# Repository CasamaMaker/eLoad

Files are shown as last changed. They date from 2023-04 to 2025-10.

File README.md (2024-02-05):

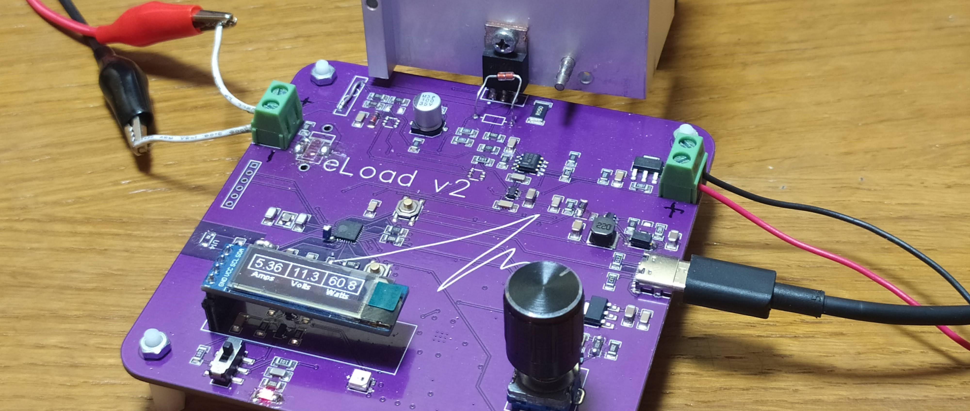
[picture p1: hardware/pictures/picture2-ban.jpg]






[__Project published on OSHWLAB__](https://oshwlab.com/canmarques/electronic-load_v2_copy)

# Electronic Load - 60W

This is a DIY project aimed at providing a practical, useful  and safe electronic load for people interested in electronics. While it is not be the most powerful electronic load available, it is designed to be easy to use and reliable, making it an excellent option for those looking for a DIY electronic load. We develop a HW and SW for complete integration, but you can use it as you want. Based in microcontroller ESP32-C3.

---

## Purpose

This project is designed for people who want to build their own electronic load for testing and evaluating power supplies, batteries, and other electronic components. It is a practical and affordable solution for those who do not want to spend a lot of money on a commercial electronic load but still want to have a reliable tool for their electronic projects.

## Features

The __Electronic Load - 60W__ has several features that make it a practical and useful tool, including:

- __25Vdc__ maximum voltage
- __5A__ maximum current
- __60W__ power output (_12V/5A_, depending on cooling system, Fan needed!!)
- Based in microcontroller __ESP32-C3__
- Reverse polarity voltage protection
- __Thermal protection__ to prevent avalanche breakdown due to temperature
- Overcurrent and overvoltage protection
- Adjustable current, voltage and power settings by fisical selector
- Switch to dis/enable load functions
- Easy-to-read display for current, voltage and power monitoring
- Easy-to-configure wifi _ssid_ and _psk_
- __Live graphic on web__ for current, tension and power monitoring
- Cooling fan output, 12Vdc/0.5A
- It is powered by a typical 5V USB-C power source

---

## Board connections
- USB to power up the LV site of board
- Vload input, where to connect the power supply to apply the load
- Power mosfet, is the main component that works in resistence part to to vary its resistance. I need a heatsink !!
- Fan output, to healp heatsink control mosfet temperature. For low power applications and having a good heatsink maybe it is not needed.
- eLoad switch enable and disable the mosfet gate directly, to stop or let run the load.

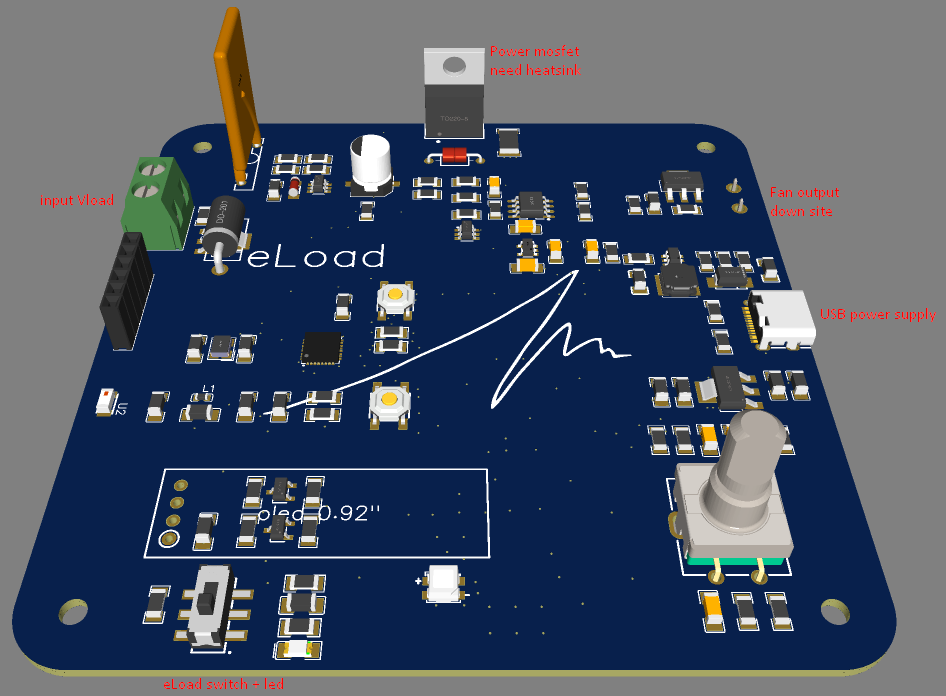
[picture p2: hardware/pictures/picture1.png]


---

## Monitoring web
When you plug in the USB power to eLoad electronics, it will start and in a few seconds will show a IP (if it can connecto to the wifi) or it wil generate an AP wifi (where you can configure wifi, if you want). At any case, you will see this website.

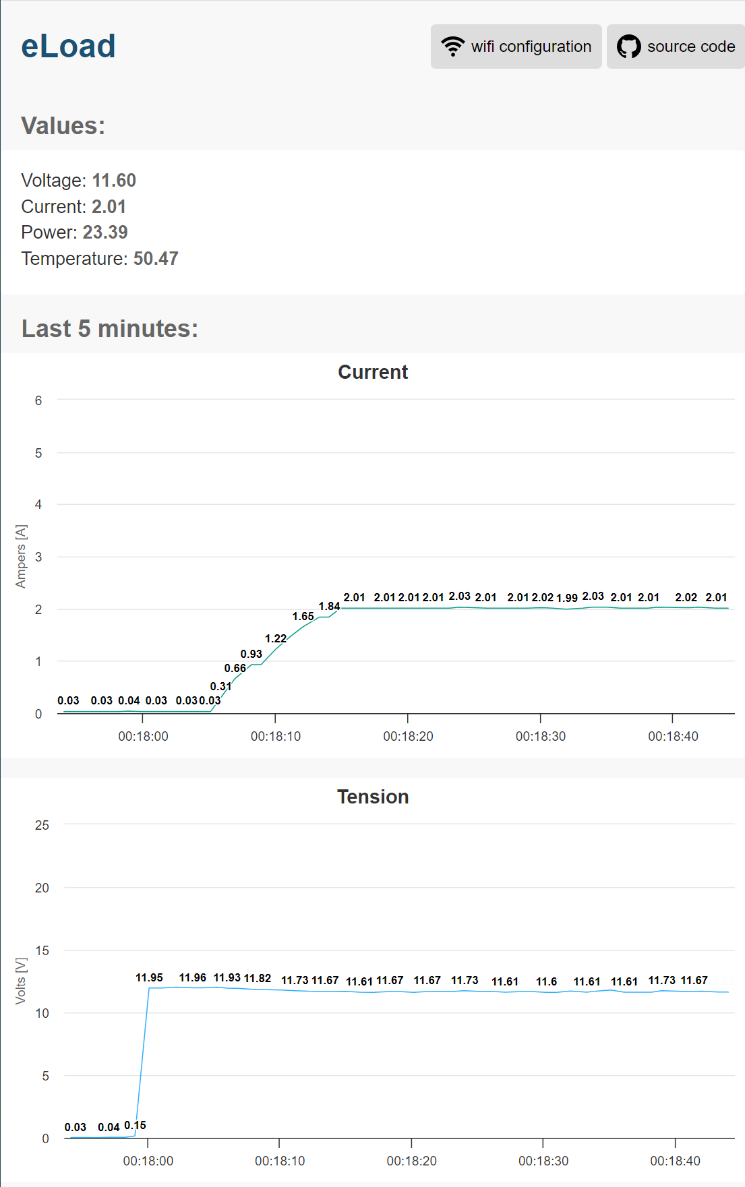
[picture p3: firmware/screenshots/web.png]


---

## Burning firmware
There are two different ways to do that, the easy&fast (using bin file) or the advance (using PlatformUO)

### Easy&Fast
- Download [Last eLoad Release](https://github.com/CanMarques/eLoad/releases)
- Download [Flash Download Tools](https://www.espressif.com/en/support/download/other-tools?keys=flash+download+tools) from ESPRESSIF
- Open Flash Download Tools -> _ESP32-C3 / Develop / USB_
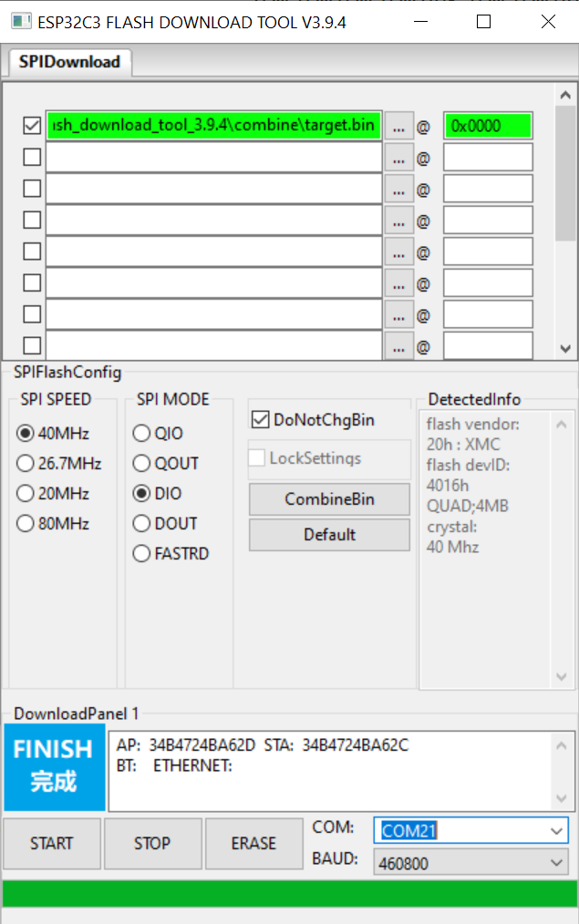
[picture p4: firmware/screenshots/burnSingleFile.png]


---

## GPIOs
|Function|GPIO|Mode|
|---|---|---
|Cooling fan|0|Output|
|ADC-Isense|1|Input|
|Digital led|2|Output|
|ADC-Vsense|3|Input|
|ADC-Tsense1|4|Input|
|Mosfet|6|Output|
|Sw sense|7|Input|
|Selector move B|8|Input|
|Selector button|9|Input|
|Selector move A|10|Input|
|I2C-SCL|20|Communication|
|I2C-SDA|21|Communication|

### Pin Details of ESP32-C3

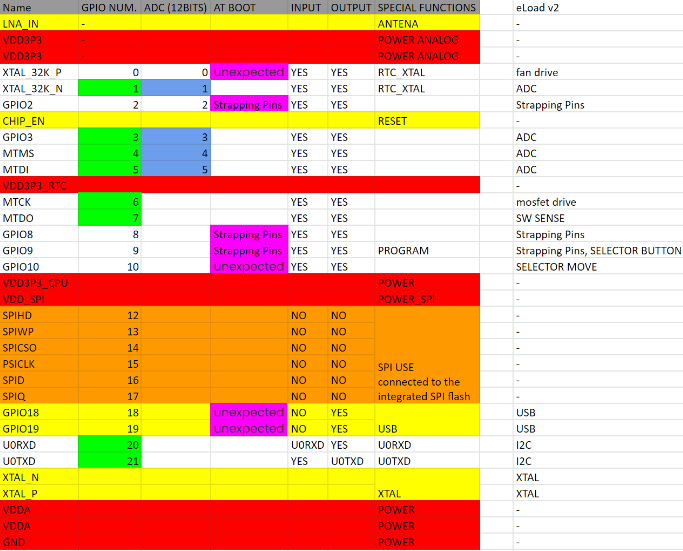
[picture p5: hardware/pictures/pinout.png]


---

## Safety

Safety is a top priority in the design of the Electronic Load - 60W. It includes HW and SW protections: HW

Resettable fuse of 6A, for overcurrent of load
Thermoswitch,
Opam,
Main switch
Thermistor sensor,
Fan
SW

Thermistor monitoring for turn on the fan when temperature increase over 50ºC and turn of pwm signal when it is over 100.
overcurrent and overvoltage protection, and is designed to be safe and reliable for DIY enthusiasts.

---

## Accuracity

It is the weak point of the ESPRESSIF microcontrollers, the internal ADC it is not accurate. In my tests, the error can be up to 10% of error, and it can change in the time. In the PCB design exist de option the use an external ADC for monitor Voltage and Current (not for temperature).

---

## To do
- Get log file .csv, via web, sd card or usb to pc
- Program option to setting up load profile in the time
- Batteries calculations
- Design of 3D printable box

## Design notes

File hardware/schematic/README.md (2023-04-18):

# Schematic description modul by modul

## Table of contents
- [Microcontroller](#microcontroller)
    - [Essentials](#essentials)
    - [Antenna design](#antena-design)
- [Drive](#drive)
- [Sensing](#sensing)

---

## Microcontroller

### Essentials
This is the essential part to work with this uC

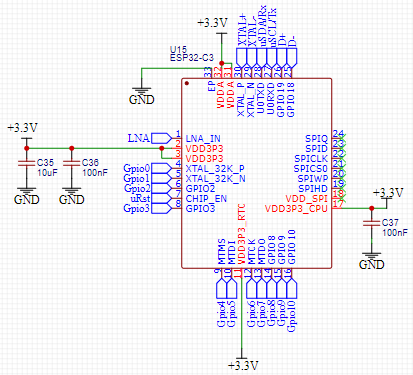
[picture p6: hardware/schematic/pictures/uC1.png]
Microcontroller


Crystal configuration, capacitors value always will depend of the choosed Xtal

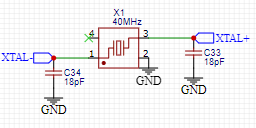
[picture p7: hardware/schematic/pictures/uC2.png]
Xtal


HW boot mode configuratinos pins for this uC

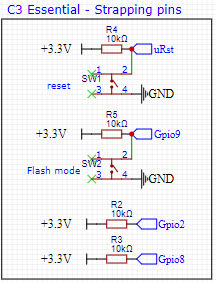
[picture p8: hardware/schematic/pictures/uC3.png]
Essential HW configuration


Pinout for normal UART programing

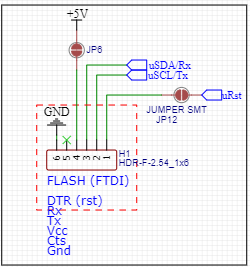
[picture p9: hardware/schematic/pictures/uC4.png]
UART flashing


### Antena design
It needs a special comment due it is delicated performance. There are differents designs types. You can found more information is these documents of [Cypress](https://www.infineon.com/dgdl/Infineon-AN91445_Antenna_Design_and_RF_Layout_Guidelines-ApplicationNotes-v09_00-EN.pdf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) and [NXP](https://www.nxp.com/docs/en/nxp/application-notes/AN11994.pdf). 

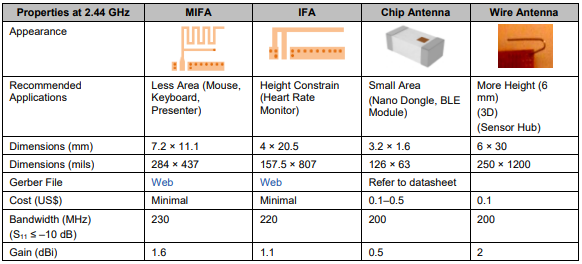
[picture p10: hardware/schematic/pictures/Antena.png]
Antennas types


We choose Chip Antenna.

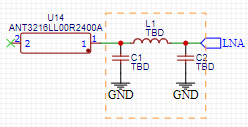
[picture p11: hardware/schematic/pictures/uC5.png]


It is important to respect pcb design, like this

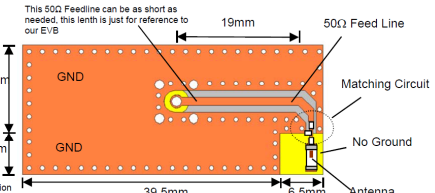
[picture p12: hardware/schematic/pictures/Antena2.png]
Reference PCB design


## Drive
__Mosfet driver__

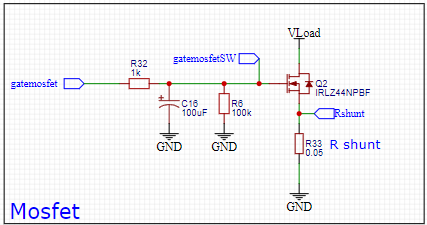
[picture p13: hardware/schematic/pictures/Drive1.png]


## Sensing
The __temperature sensing__ of the mosfet, to prevent it archive the maximum temperature and be damaged, also with that information we can manage the fan. For now it is just a voltage divider directo to uC ADC input, but _It need to be improve_ with opam configuration.

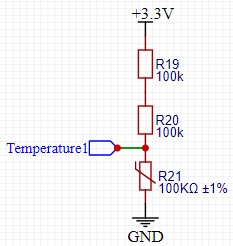
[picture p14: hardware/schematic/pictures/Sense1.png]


The are 3 parts in the __Load voltage sensing__ a simple voltage divider, an overvoltage protection and optional external ADC chip. As it is works fine but with a little distorcion when load is working. _Will be improved with opam circuit_

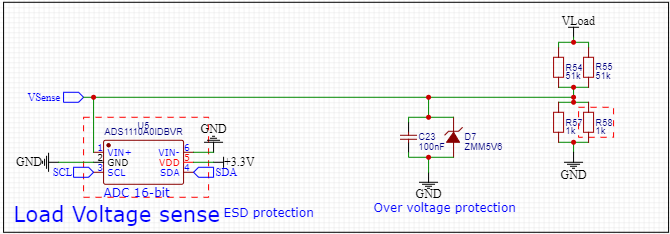
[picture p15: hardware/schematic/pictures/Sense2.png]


This is an optional extanal ADC chip for Current sense, but for the moment we do not use.



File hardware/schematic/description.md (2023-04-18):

# Schematic description modul by modul

## Microcontroller

This is the essential part to work with this uC


crystal configuration, capacitors value always will depend of the choosed Xtal


HW boot mode configuratinos pins for this uC


Pinout for normal UART programing


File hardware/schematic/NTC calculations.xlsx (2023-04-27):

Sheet: TH voltage divider
ºC | Ω | Steinhart-Hart | error S-H | Simplificada | error Simplificada | voltage ADC | v/step | https://www.jameco.com/Jameco/workshop/TechTip/temperature-measurement-ntc-thermistors.html
25 | 100000 | 25.00000002 | -7.597054719e-08 | 25 | 0 | 1.1 | TRUE
26 | 95786 | 25.99792186 | 0.007992830609 | 25.97206687 | 0.107443703 | 1.06865707 | TRUE
27 | 91767 | 26.99572732 | 0.01582473079 | 26.94616403 | 0.199424056 | 1.037921012 | TRUE
28 | 87932 | 27.99374027 | 0.02235619623 | 27.92261457 | 0.2764383347 | 1.007792118 | TRUE
29 | 84272 | 28.99193549 | 0.02780864579 | 28.90140174 | 0.3400885809 | 0.9782799572 | TRUE
30 | 80779 | 29.99013109 | 0.03289637344 | 29.88235436 | 0.3922811899 | 0.9493968566 | TRUE
31 | 77443 | 30.98886281 | 0.03592642882 | 30.86600729 | 0.4323898969 | 0.9211329895 | TRUE
32 | 74258 | 31.98762455 | 0.0386732906 | 31.85187052 | 0.4630837025 | 0.8935068439 | TRUE
33 | 71215 | 32.98695396 | 0.03953344725 | 32.84048334 | 0.4835749989 | 0.8665062773 | TRUE
34 | 68309 | 33.98621921 | 0.04053172765 | 33.83122892 | 0.496586816 | 0.8401496036 | TRUE
35 | 65532 | 34.98590284 | 0.04027759241 | 34.82459345 | 0.5013635051 | 0.8144238736 | TRUE
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

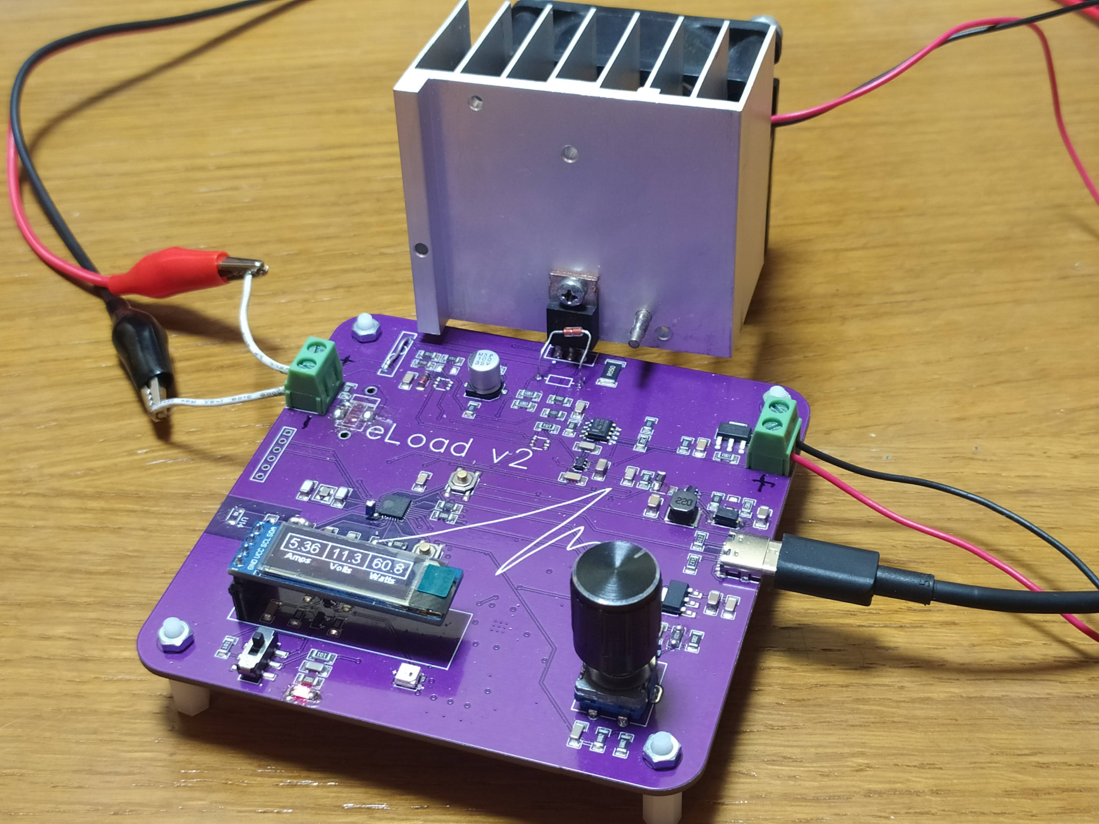
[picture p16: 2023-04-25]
hardware/pictures/picture2.jpg

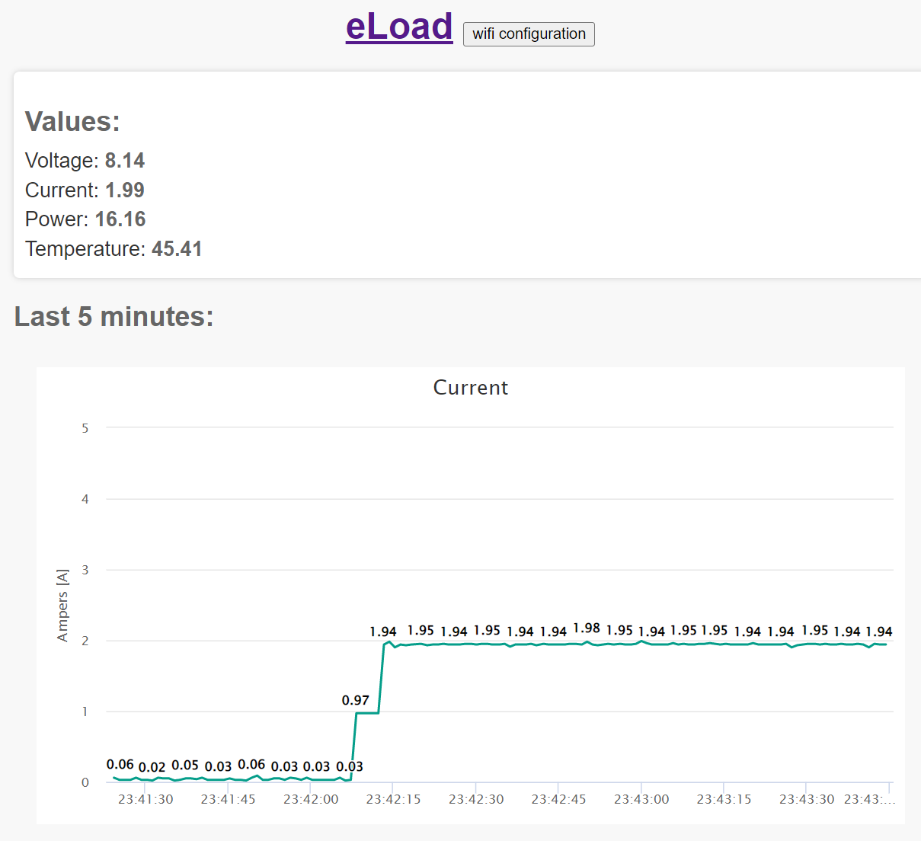
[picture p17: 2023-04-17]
hardware/pictures/web.png

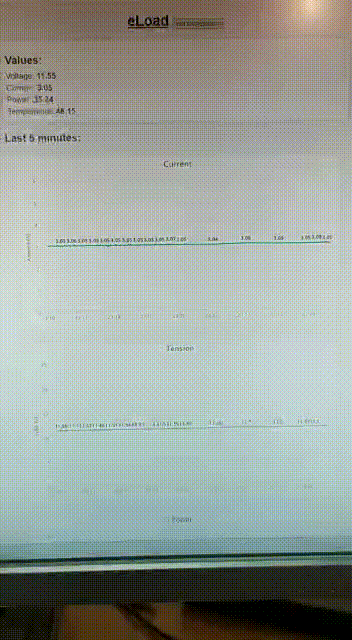
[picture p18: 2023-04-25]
hardware/pictures/gift-web.gif

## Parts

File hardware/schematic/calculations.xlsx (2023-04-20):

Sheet: Vload sense
Voltage divider |  |  |  |  |  | Resistance worse case
 | Option 1 | Option 2
Vin | 26.5 | 68.9 | V
Vout | 1 | 2.6 | V |  |  | resistors error | 1.00 %
R1 | 25500 | 25500 | R | R1 = (R2*Vin/Vout)-R2 |  |  | 25755 | 25245
R2 | 1000 | 1000 | R |  |  |  | 1010 | 990
Vread calculation |  |  |  |  |  | Deviation V | 10.20953984 | 9.816611661
bitsAdc | 4095 | 4095 | bits |  |  | Deviation % | -1.982085001 | 1.942835793
readAdc | 665 | 595 | bits
readV | 4.303418803 | 10.01111111 | V | readV = readAdc * (max Vadc/bitsAdc)*(R1+R2/R2)
Vread resolution
resolutionADC | 0.0002442002442 | 0.0006349206349 | V
resolutionVload | 0.006471306471 | 0.01682539683 | V |  |  | ADC ESP32-C3 reality case
 |  |  |  |  |  | Vreal | 0.9 | 0.47 | 0.188
 |  |  |  |  |  | Vread | 0.8 | 0.42 | 0.17
 |  |  |  |  |  | Deviation % | 0.1111111111 | 0.1063829787 | 0.09574468085
 |  |  |  |  | 1,05A
 |  |  |  | shunt | 0.115
 |  |  |  |  | 0.276
 |  |  |  | 24
 |  |  |  | 23.58
 |  |  |  | 1.017811705

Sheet: Temp sense
Voltage divider
 | Option 1 | Option 2
Vin | 3.3 | 3.3 | V
Vout | 1 | 3.3 | V
R1 | 230000 | 0 | R | R1 = (R2*Vin/Vout)-R2
R2 | 100000 | 100000 | R | Thermistor
Vread calculation
bitsAdc | 4095 | 4095 | bits
readAdc | 4095 | 4095 | bits
readV | 3.3 | 3.3 | V | readV = readAdc * (max Vadc/bitsAdc)*(R1+R2/R2)
Tread calculation - Steinhart-Hart
Thermistor resistance |  |  | 90000 | R
Vcc |  |  | 3.3 | V
Thermistor nominal |  |  | 100000 | R
Temperature nominal |  |  | 25 | ºC
B_coeficient |  |  | 3950
TemperatureCelciu |  |  | 26.03332587 | ºC | TemperatureCelcius = 1/(((log(resistance / THERMISTOR_NOMINAL))/B_COEFFICIENT)+1.0 / (TEMPERATURE_NOMINAL + 273.15))-273.15

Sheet: DriveMosfetFeedback+Iload sense
Mosfet Feedback |  |  |  |  |  |  |  |  |  |  | Ampli opam
 | op1 | op2 |  |  |  |  |  |  |  |  |  | Option 1 | Option 2
opam signal input | 3.3 | 3.3 | V |  |  |  |  |  |  |  | Rshunt | 0.05 | 0.05 | R
Vload max | 25 | 25 | V |  |  |  |  |  |  |  | Imax | 5 | 5 | A
Iload max | 5 | 5 | A |  |  |  |  |  |  |  | Vin | 0.25 | 0.25 | V
Rshunt | 0.05 | 0.05 | R |  |  |  |  |  |  |  | Vout | 1 | 3.3 | V | Vout=Vin*(1+R2/R1)
Vshunt max | 0.25 | 0.25 | V |  |  |  |  |  |  |  | multi (Vin*n) | 4 | 13.2 | x
Wshunt | 1.25 | 1.25 | W
Vadc max | 1 | 3.3 | V |  |  |  |  |  |  |  | Opam ampli no negative Resistors
 |  |  |  |  |  |  |  |  |  |  | R1 | 1000 | 1000 | R
 | Vload |  |  |  |  |  |  |  |  | mosfet gate | R2 | 3000 | 12200 | R | R2=(Vout/Vin-1)*R1
flowing Amps
2 |  |  |  |  | opam ampli |  |  | opam ampli |  |  | Vread calculation
 | mosfet |  |  |  |  |  |  |  |  |  | bitsAdc | 4095 | 4095 | bits
 |  |  | max | 0.25 |  | max | 1 |  | max | 3.3 | readAdc | 20 | 4095 | bits
 |  |  | Vread | 0.1 | 4 |  |  | 3.3 |  | 1.32 | readV | 0.001221001221 | 0.25 | V | readV = readAdc * (max Vadc/bitsAdc)*(R1+R2/R2)
 | Rshunt |  |  |  |  |  |  |  |  |  | readAmps | 0.02442002442
 | gnd |  |  |  |  | uC adc
 |  |  |  |  |  | 0.4
 |  |  |  |  |  |  |  |  |  |  | Vread resolution
 |  |  |  |  |  |  |  |  |  |  | resolutionADC | 0.2442002442 | 0.8058608059 | mV
 |  |  |  |  |  |  |  |  |  |  | resolutionVshunt | 0.06105006105 | 0.06105006105 | mV
 |  |  |  |  |  |  |  |  |  |  | resolutionAmps | 1.221001221 | 1.221001221 | mA

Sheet: Snubber filter RC
Low pass
R | 10000 | R
C | 1e-07 | F
Fc | 159.1549431 | Hz
Freq [Hz] | Modul [Vo/Vi] | Modul [dB]
1 | 0.9999802614 | -0.0001714492049
10 | 0.9980319045 | -0.01711150434
100 | 0.846733016 | -1.445070116
1000 | 0.1571767255 | -16.07223527
10000 | 0.01591347897 | -35.96469731
100000 | 0.001591547415 | -55.96360837
1000000 | 0.0001591549411 | -75.96359748

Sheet: PowerSupply-Boost
R2 calculation
Vout | 12 | V | Vout=Vref(1+R1/R2)
Vref | 0.6 | V
R1 | 19000 | R | R1=R2(Vout/Vref-1)
R2 | 1000 | R | R2=R1/(Vout/Vref-1)
Vout calculation
Vout | 12.6 | V | Vout=Vref(1+R1/R2)
Vref | 0.6 | V
R1 | 20000 | R | R1=R2(Vout/Vref-1)
R2 | 1000 | R | R2=R1/(Vout/Vref-1)

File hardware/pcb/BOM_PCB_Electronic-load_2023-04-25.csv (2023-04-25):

ID | Name | Designator | Footprint | Quantity | Manufacturer Part | Manufacturer | Supplier | Supplier Part | Price
1 | TBD | L1 | L0603 | 1
2 | 18pF | C1,C2 | C1206 | 2 | 1206CG100J500NT | FH | LCSC | C1883 | 0.002
3 | 10uF | C3 | C1206 | 1 | CL31A106KBHNNNE | SAMSUNG | LCSC | C13585 | 0.005
4 | 100nF | C4,C5,C8,C10,C14,C21,C23 | C1206 | 7 | CL31B104KBCNNNC | SAMSUNG | LCSC | C24497 | 0.002
5 | TBD | C6 | C1206 | 1 | CL31A106KBHNNNE | SAMSUNG | LCSC | C13585 | 0.005
6 | TBD | C7 | C1206 | 1 | CL31B104KBCNNNC | SAMSUNG | LCSC | C24497 | 0.002
7 | 10nF | C9,C11,C12 | C1206 | 3 | CL31B105KBHNNNE | SAMSUNG | LCSC | C1848 | 0.003
8 | 10nF | C13 | C1206 | 1 | CL31B104KBCNNNC | SAMSUNG | LCSC | C24497 | 0.002
9 | 100uF | C15 | CAP-SMD_BD6.3-L6.6-W6.6-LS7.6-FD | 1 | UWT1V101MCL1GS | Nichicon | LCSC | C125975 | 0.013
10 | 10uF | C16 | C1206 | 1
11 | 100nF | C17 | C1206 | 1
12 | 0.1u | C18,C19 | C1206 | 2 | TCC1206X7R104K451HT | CCTC | LCSC | C359183 | 0.003
13 | 0.1u | C20 | C1206 | 1
14 | 10uF | C22,C24 | C1206 | 2 | CL31B105KBHNNNE | SAMSUNG | LCSC | C1848 | 0.003
15 | 22uF | C25,C26 | C1206 | 2 | CL31A226KPHNNNE | SAMSUNG | LCSC | C5672 | 0.004
16 | ZMM5V6 | D1 | LL-34_L3.5-W1.5-RD | 1 | ZMM5V6 | SEMTECH | LCSC | C8062 | 0.002
17 | HER505 | D2 | DO-201AD_BD5.3-L8.4-P12.50-D1.4-RD | 1 | HER505 | (MDD) Jiangsu Yutai Elec | LCSC | C364262 | 0.014
18 | SS34_C8678 | D3 | DO-214AC_L4.3-W2.7-LS5.3-RD | 1 | SS34 | MDD | LCSC | C8678 | 0.005
19 | WS2812B-MINI | LED1 | LED-SMD_4P-L3.5-W3.5-TL_WS2812B | 1 | WS2812B-Mini | Worldsemi | LCSC | C527089 | 0.017
20 | SZYY1206G | LED2 | LED1206-R-RD | 1 | SZYY1206G | Yongyu Photoelectric | LCSC | C434439 | 0.003
21 | BSS138_C112239 | Q1,Q2 | SOT-23-3_L2.9-W1.6-P1.90-LS2.8-BR | 2 | BSS138 | SK | LCSC | C112239 | 0.004
22 | NCE6005AR | Q3 | SOT-223_L6.5-W3.5-P2.30-LS7.0-BR | 1 | NCE6005AR | Wuxi NCE Power Semiconductor | LCSC | C189606 | 0.028
23 | NCE6005AR | Q4 | SOT-223_L6.5-W3.5-P2.30-LS7.0-BR | 1 | NCE6005AR | NCE(无锡新洁能) | LCSC | C189606 | 0.028
24 | IRLZ44NPBF | Q5 | TO-220-3_L10.0-W4.5-P2.54-T | 1 | IRLZ44NPBF | Infineon(英飞凌) | LCSC | C38774 | 0.165
25 | 10kΩ | R1,R2,R3,R4 | R1206 | 4 | 1206W4F1002T5E | UniOhm | LCSC | C17902
26 | 51k | R5,R6 | R1206 | 2 | 1206W4F5102T5E | UniOhm | LCSC | C17992 | 0.001
27 | 1k | R7,R8,R43 | R1206 | 3 | 1206W4F1001T5E | UniOhm | LCSC | C4410
28 | 100k | R9,R10 | R1206 | 2 | 1206W4F5102T5E | UniOhm | LCSC | C17992 | 0.001
29 | 100KΩ ±1% | R11 | RES-TH_BD2.5-L4.7-P8.70-D0.5 | 1 | MF58 104F3950 | Nanjing Shiheng Elec | LCSC | C123399 | 0.007
30 | 10k | R12,R13,R14,R15,R16,R17,R18,R19,R20,R21,R24,R25 | R1206 | 12 | 1206W4F1002T5E | UniOhm | LCSC | C17902
31 | 100 | R22,R23 | R1206 | 2 | 1206W4F1002T5E | UniOhm | LCSC | C17902
32 | 10k | R26 | R1206 | 1 | 1206W4F3302T5E | UniOhm | LCSC | C18004 | 0.001
33 | 100k | R27 | R1206 | 1 | 1206W4F1002T5E | UniOhm | LCSC | C17902
34 | 1k | R28 | R1206 | 1 | 1206W4F3302T5E | UniOhm | LCSC | C18004 | 0.001
35 | 100k | R29 | R1206 | 1 | 1206W4F3302T5E | UniOhm | LCSC | C18004 | 0.001
36 | 0.05 | R30 | R2512 | 1 | MRF6432(2512)LR070FTS | SUP | LCSC | C76251 | 0.017
37 | 10k | R31 | R1206 | 1 | 1206W4F3001T5E | UniOhm | LCSC | C18012
38 | 100 | R32 | R1206 | 1 | 1206W4F3001T5E | UniOhm | LCSC | C18012
39 | 2k | R33 | R1206 | 1 | 1206W4F3001T5E | UniOhm | LCSC | C18012
40 | 3k | R34 | R1206 | 1 | 1206W4F3001T5E | UniOhm | LCSC | C18012
41 | 10k | R35,R42 | R1206 | 2
42 | 1k | R36,R37 | R1206 | 2 | 1206W4F3001T5E | UniOhm | LCSC | C18012
43 | 5k1 | R38,R39 | R1206 | 2 | 1206W4F1002T5E | UniOhm | LCSC | C17902
44 | 12k | R40 | R1206 | 1 | 1206W4F1002T5E | UniOhm | LCSC | C17902
45 | 20k | R41 | R1206 | 1 | 1206W4F1002T5E | UniOhm | LCSC | C17902
46 | PEC11R-4015F-S0024 | SW4 | SW-TH_PEC11R-4XXXF-SXXXX | 1 | PEC11R-4015F-S0024 | BOURNS | LCSC | C143789 | 0.376
47 | JS202011SCQN | SW5 | SW-SMD_JS202011SCQN | 1 | JS202011SCQN | C&K | LCSC | C221666 | 0.083
48 | ESP32-C3 | U1 | QFN-32_L5.0-W5.0-P0.50-TL-EP3.7 | 1 | ESP32-C3 | ESPRESSIF 乐鑫 | LCSC | C2838500 | 0.188
49 | ANT3216LL00R2400A | U2 | ANT-SMD_L3.2-W1.6 | 1 | ANT3216LL00R2400A | YAGEO | LCSC | C293767 | 0.019
50 | ADS1110A0IDBVR | U3 | SOT-23-6_L2.9-W1.6-P0.95-LS2.8-BR | 1 | ADS1110A0IDBVR | TI(德州仪器) | LCSC | C16598 | 0.277
51 | ADS1110A2IDBVT | U4 | SOT-23-6_L2.9-W1.6-P0.95-LS2.8-BR | 1 | ADS1110A2IDBVT | TI(德州仪器) | LCSC | C94790 | 0.845
52 | Oled 0,91x32 | U5 | OLED 0.92" | 1
53 | KF127-5.08-2P | U7,U6 | CONN-TH_P5.08_KF127-5.08-2P | 2 | KF127-5.08-2P | Cixi Kefa Elec | LCSC | C474906 | 0.024
54 | LM321MF | U8 | SOT-23-5_L2.9-W1.6-P0.95-LS2.8-BL | 1 | LM321MF | UMW(Youtai Semiconductor Co., Ltd.) | LCSC | C668208 | 0.006
55 | LM358DR2G | U9 | SOIC-8_L5.0-W4.0-P1.27-LS6.0-BL | 1 | LM358DR2G | onsemi(安森美) | LCSC | C7950 | 0.025
56 | AMS1117-3.3 | U10 | SOT-223-3_L6.5-W3.4-P2.30-LS7.0-BR | 1 | AMS1117-3.3 | AMS | LCSC | C6186 | 0.024
57 | MT3608L | U11 | SOT-23-6_L2.9-W1.7-P0.95-LS2.8-BL | 1 | MT3608L | 西安航天民芯 | LCSC | C2932326 | 0.01
58 | JK30-500_C369108 | F1 | FUSE-TH_L14.0-W3.0-P10.20-D1.2-S1.2 | 1 | JK30-500 | JK(金科) | LCSC | C369108 | 0.016
59 | HDR-F-2.54_1x6 | H1 | HDR-F-2.54_1X6 | 1 | Female header 1*6p | BOOMELE | LCSC | C40877 | 0.012
60 | 22uH | L2 | IND-SMD_L5.0-W5.0 | 1 | SWPA5040S220MT | Sunlord | LCSC | C68434 | 0.011
61 | ST-1187-2.5 | SW1,SW2 | SW-SMD_4P-L5.2-W5.2-P3.70-LS6.5 | 2 | ST-1187-2.5 | RISHENG(日昇) | LCSC | C589208 | 0.007
62 | USB-TYPE-C-018 | USB1 | USB-C_SMD-TYPE-C-31-M-12 | 1 | USB-TYPE-C-018 | DEALON(德艺隆) | LCSC | C2927038 | 0.008
63 | 40MHz | X1 | CRYSTAL-SMD_4P-L3.2-W2.5-BL | 1 | 3TJ412000UYFBC | JYJE(晶友嘉) | LCSC | C2681245 | 0.02

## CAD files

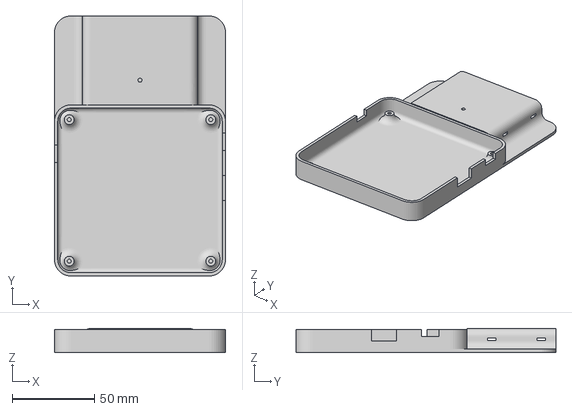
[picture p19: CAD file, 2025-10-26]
Body1.3mf
104.0 x 158.0 x 14.6 mm

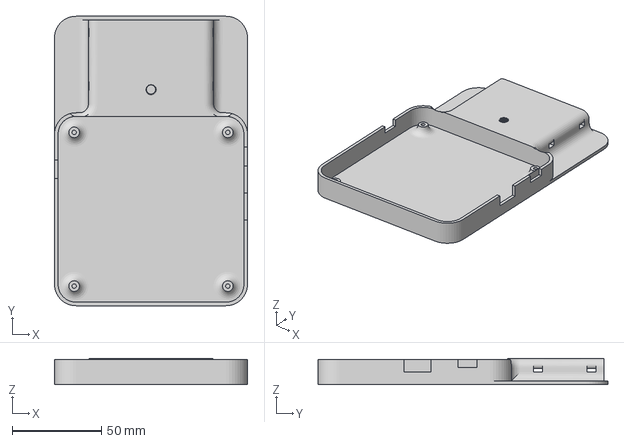
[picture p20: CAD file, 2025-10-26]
Body1.2.3mf
108.0 x 162.0 x 14.6 mm

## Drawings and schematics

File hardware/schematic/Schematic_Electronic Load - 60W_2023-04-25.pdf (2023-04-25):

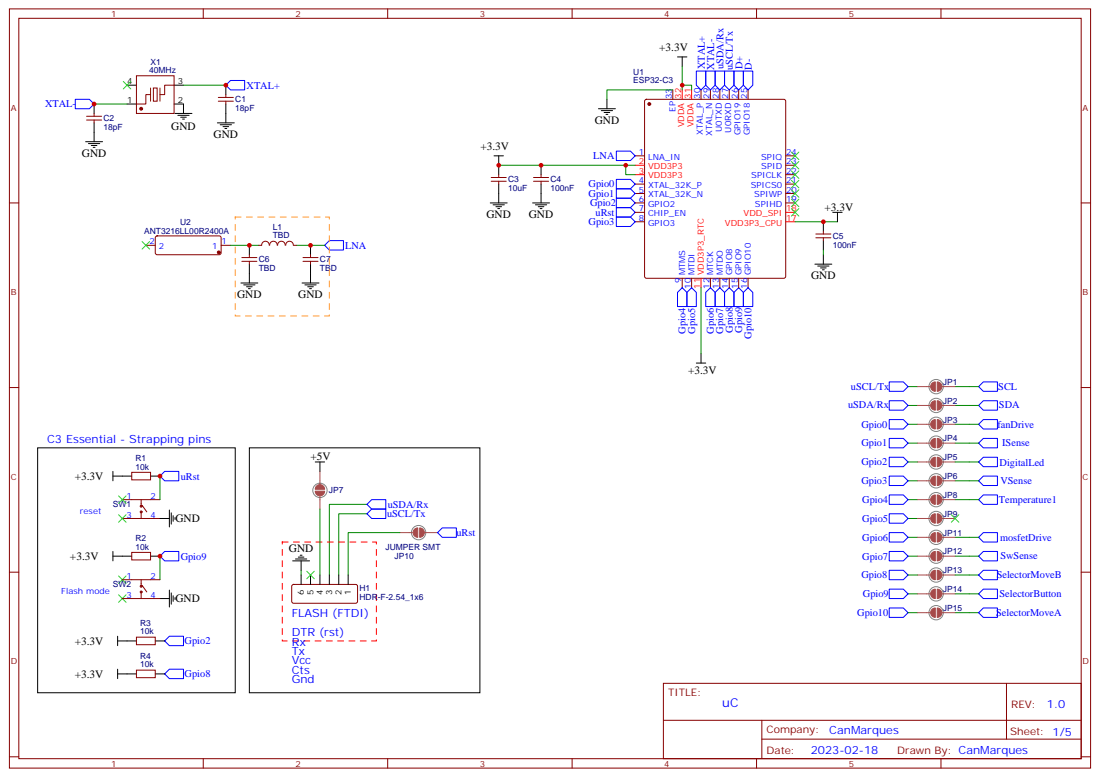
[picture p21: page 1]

VDD3P3_CPU 17 VDD_SPI 18 SPIHD 19 SPIWP 20 SPICS0 21 SPICLK 22 SPID 23 SPIQ 24 GPIO¹⁸ ²⁵ GPIO¹⁹ ²⁶ U⁰RXD ²⁷

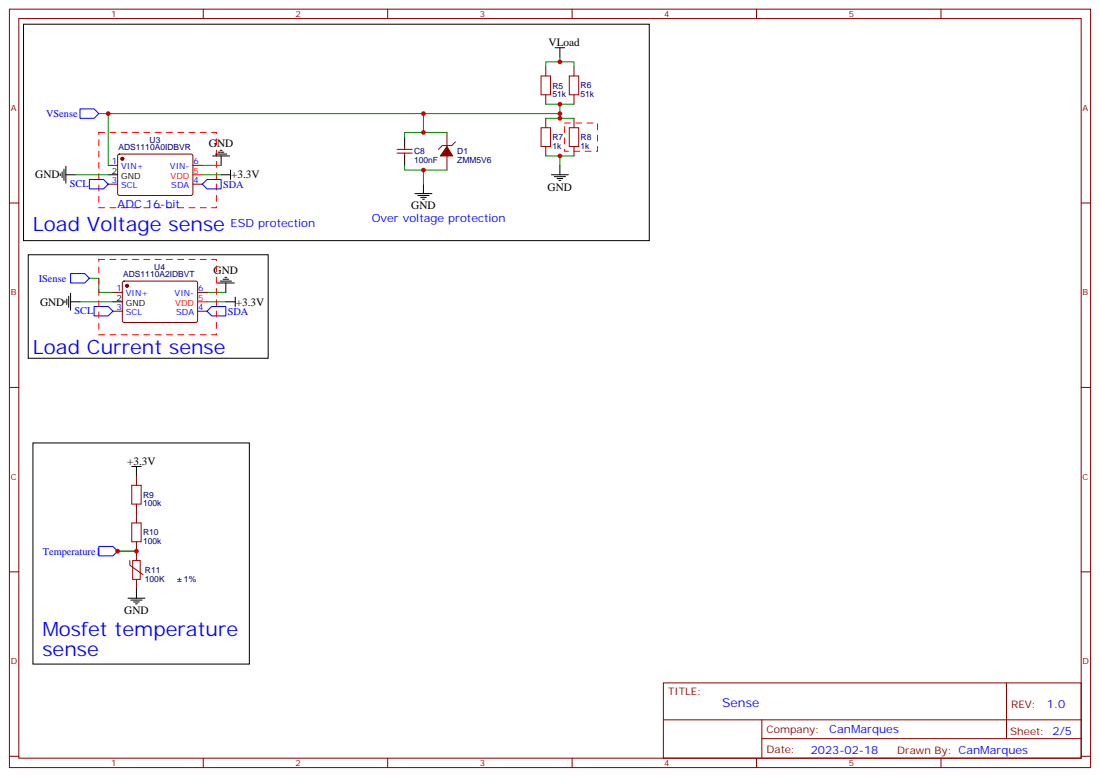
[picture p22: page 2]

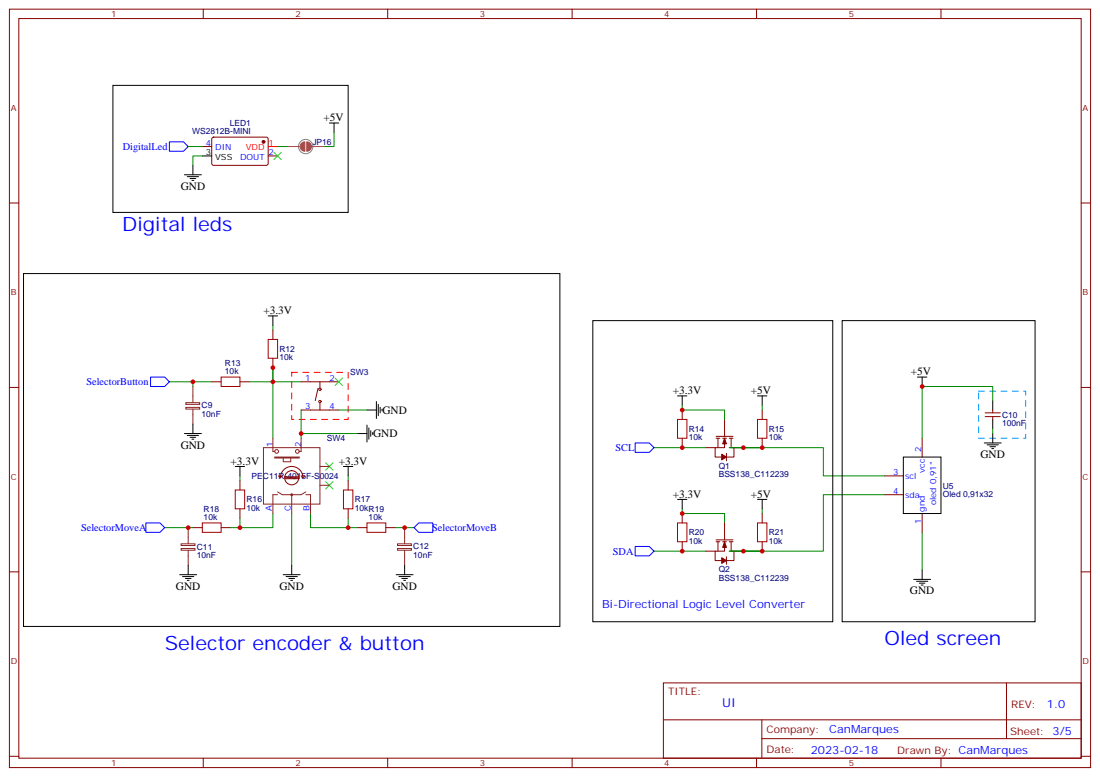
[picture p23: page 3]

Bi-Directional Logic Level Converter

# Company: CanMarques power8

## VLoad DC

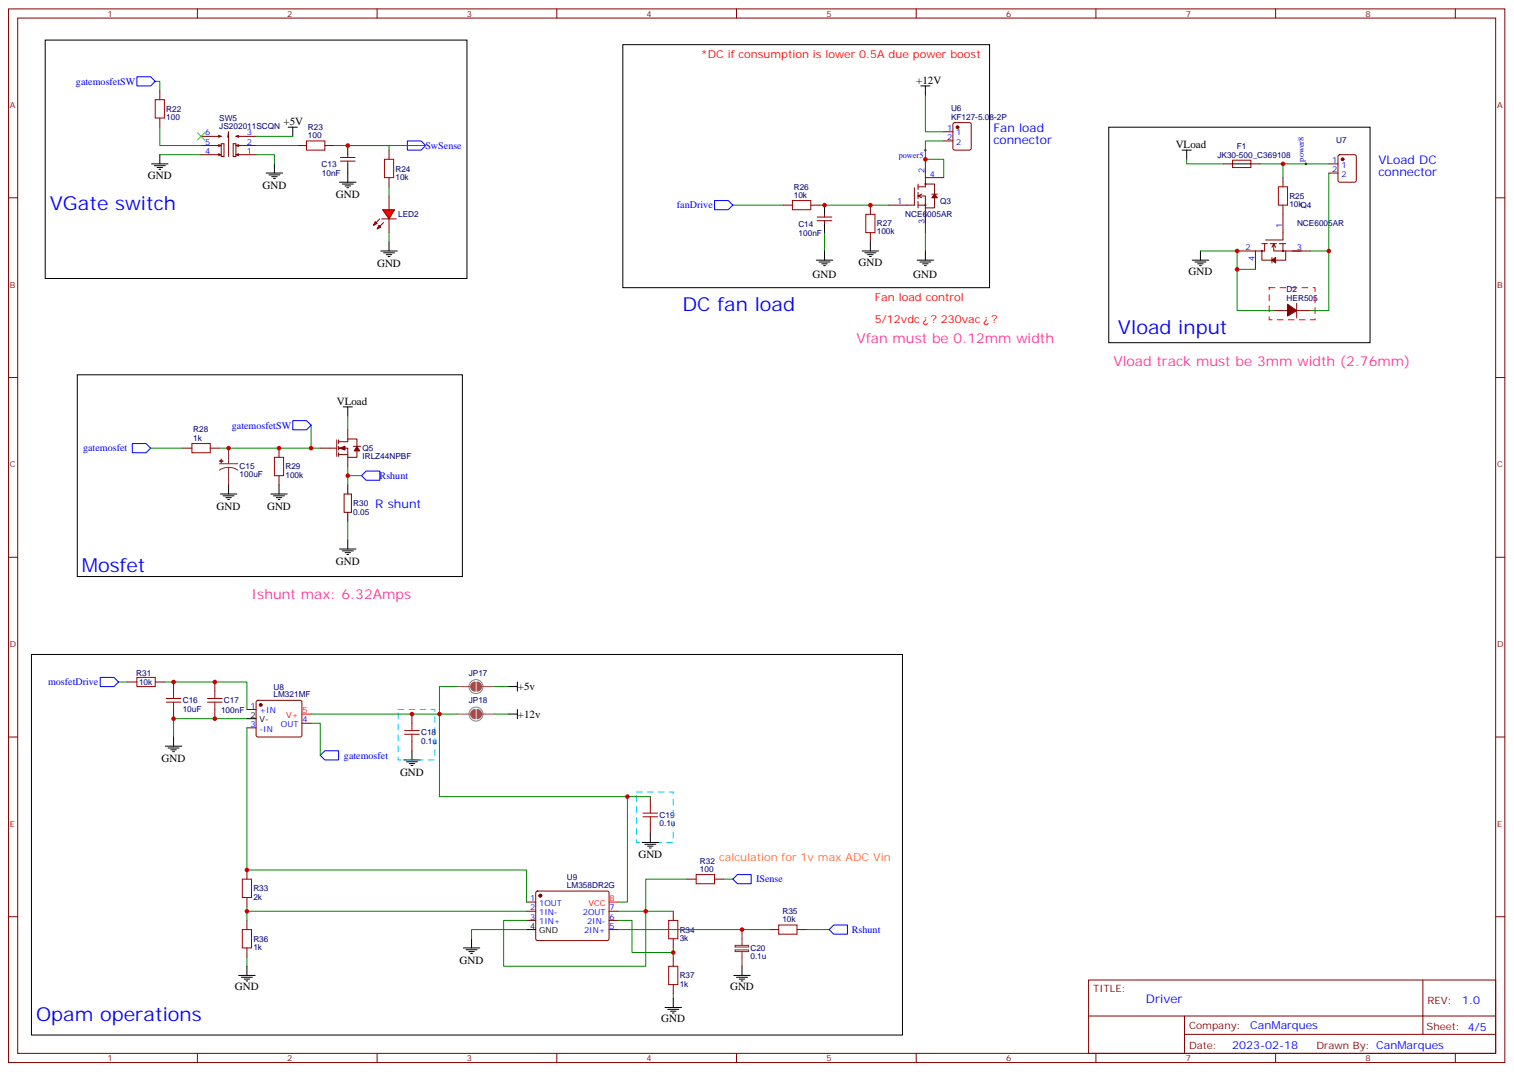
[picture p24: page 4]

*DC if consumption is lower 0.5A due power boost

GND
Fan load control
5/12vdc ? 230vac ?
Vfan must be 0.12mm width

Vload track must be 3mm width (2.76mm)

R32 calculation for 1v max ADC Vin

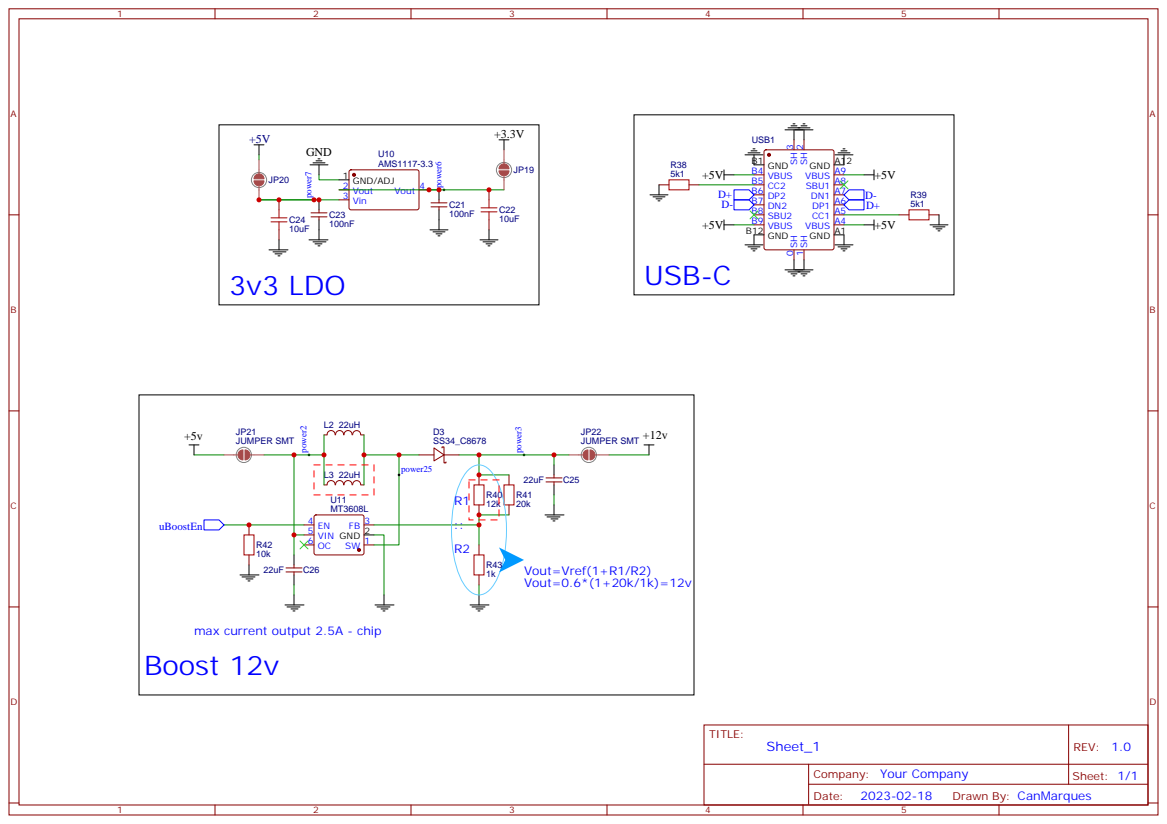
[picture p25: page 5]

max current output 2.5A - chip
Boost 12v

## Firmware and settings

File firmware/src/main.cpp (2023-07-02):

#include <Arduino.h>


//******************* PINOUT ********************//
#define FAN_PIN               0
#define ISENSE_PIN            1
#define DIGITAL_LED_PIN       2
#define VSENSE_PIN            3 
#define TSENSE_PIN            4
#define MOSFET_PIN            6
#define GATE_SWITCH_PIN       7
#define PWM_PIN               6
#define SELECTOR_MOVE_B_PIN   8
#define SELECTOR_BUTTON_PIN   9
#define SELECTOR_MOVE_A_PIN   10


//******************* PANTALLA OLED ********************//
#include "SSD1306Wire.h"
#include "pantallaOled.h"
SSD1306Wire display(0x3c, 21, 20, GEOMETRY_128_32);


//***************** WIFI MANAGER **********************//
#include <wifimanager.h>
#include <WiFi.h>
#include <ESPAsyncWebServer.h>
#include <AsyncTCP.h>
#include "SPIFFS.h"
AsyncWebServer server(80);  // Create AsyncWebServer object on port 80
const char* PARAM_INPUT_1 = "ssid";// Search for parameter in HTTP POST request
const char* PARAM_INPUT_2 = "pass";
String ssid;//Variables to save values from HTML form
String pass;
const char* ssidPath = "/ssid.txt";// File paths to save input values permanently
const char* passPath = "/pass.txt";
IPAddress localIP;
unsigned long previousMillis = 0;// Timer variables
const long interval = 10000;  // interval to wait for Wi-Fi connection (milliseconds)
String adresa;

//****************** DIGITAL LED ******************************
/*#include <FastLED.h>
#define NUM_LEDS 1
#define DATA_PIN 2
#define BRIGHTNESS  15
CRGB leds[NUM_LEDS];*/


//********************** SENSING *******************
#include "sense.h"
#include <Wire.h>
int PWM = 0;
float amps, volts, watts;   //eload measurements
unsigned long currentTime;
#define oneSecondTime 1000
float temperature;          //ntc
bool gateSwitch;            //switch sense
#include <RotaryEncoder.h>
#define timeThreshold 5
long timeCounter = 0;
const int maxSteps = 255;
volatile int ISRCounter = 0;
int counter = 0;
bool button;
bool IsCW = true;


//******************** SELECTOR ***********************
void doEncode(){
  if (millis() > timeCounter + timeThreshold){
    if (digitalRead(SELECTOR_MOVE_A_PIN) == digitalRead(SELECTOR_MOVE_B_PIN)){
      IsCW = true;
      if (ISRCounter + 1 <= maxSteps) ISRCounter++;
    }else{
      IsCW = false;
      if (ISRCounter - 1 > 0) ISRCounter--;
    }
    PWM = ISRCounter;
    analogWrite(PWM_PIN,PWM);
    timeCounter = millis();
  }
}

bool botoInici = false;
void encoderButton(){
  if (millis() > timeCounter + timeThreshold){
    button = true;
    timeCounter = millis();
  }
  botoInici=true;
  //Serial.print("*****"); 
}




//******************** TIMER INTERRUPTION ***********************
#define TIMER_INTERRUPT_DEBUG         0
#define _TIMERINTERRUPT_LOGLEVEL_     4
#include "ESP32_C3_TimerInterrupt.h"
float lastTemperature;
bool IRAM_ATTR TimerHandler0(void * timerNo)
{
//******************** PROTECTIONS ***********************
  if(temperature > 40) digitalWrite(FAN_PIN, HIGH);     //Start fan
  if(temperature < 40) digitalWrite(FAN_PIN, LOW);      //Stop fan
  if(temperature > 120) analogWrite(PWM_PIN,0);          //Stop mosfet as load
  //if(temperature > lastTemperature + 10) analogWrite(PWM_PIN,PWM/2);
  if(temperature < 60) analogWrite(PWM_PIN,PWM);        //Restart mosfet
  if(watts > 65){
    PWM -=10;
    analogWrite(PWM_PIN,PWM);                           //Restart mosfet
  }
  //if(watts < 60) analogWrite(PWM_PIN,PWM);              //Restart mosfet
  //if(!gateSwitch) analogWrite(PWM_PIN,0);


	return true;
}

#define TIMER0_INTERVAL_MS        1000
ESP32Timer ITimer0(0);


//******************** SETUP ****************************** SETUP **************************** SETUP **********************************
void setup() {
  
  //Serial.begin(115200);             //Serial config

  display.init();                   //oled config
  display.flipScreenVertically();   //flip display option !!!
  imprimeixOled("eLOAD v1", display);

  pinMode(FAN_PIN, OUTPUT);         //Cooling fan
  pinMode(PWM_PIN, OUTPUT);         //pwm
  
  //digitalWrite(0, HIGH);
  pinMode(SELECTOR_MOVE_A_PIN, INPUT);
  pinMode(SELECTOR_MOVE_B_PIN, INPUT);
  pinMode(SELECTOR_BUTTON_PIN, INPUT);
  pinMode(GATE_SWITCH_PIN, INPUT);

  analogSetAttenuation(ADC_2_5db);  //https://randomnerdtutorials.com/esp32-adc-analog-read-arduino-ide/


  //WiFi.setHostname("my-esp32");   //not work


//******************** SPIFFS ***********************
  initSPIFFS();
  // Load values saved in SPIFFS
  ssid = readFile(SPIFFS, ssidPath);
  pass = readFile(SPIFFS, passPath);


//****************************** WEB PAGE ***********************
  if(initWiFi(ssid, pass, previousMillis, interval)) {  
    server.on("/", HTTP_GET, [](AsyncWebServerRequest *request) {
      request->send(SPIFFS, "/index.html", "text/html");
    });

    server.serveStatic("/", SPIFFS, "/");

    server.on("/readA", HTTP_GET, [](AsyncWebServerRequest *request) {
      request->send_P(200, "text/plain", String(amps).c_str());
    });

    server.on("/readV", HTTP_GET, [](AsyncWebServerRequest *request) {
      request->send_P(200, "text/plain", String(volts).c_str());
    });

    server.on("/readP", HTTP_GET, [](AsyncWebServerRequest *request) {
      request->send_P(200, "text/plain", String(watts).c_str());
    });

    server.on("/readT", HTTP_GET, [](AsyncWebServerRequest *request) {
      request->send_P(200, "text/plain", String(temperature).c_str());
    });

    server.on("/current", HTTP_GET, [](AsyncWebServerRequest *request) {
      request->send_P(200, "text/plain", String(amps).c_str());
    });

    server.on("/tension", HTTP_GET, [](AsyncWebServerRequest *request) {
      request->send_P(200, "text/plain", String(volts).c_str());
    });

    server.on("/power", HTTP_GET, [](AsyncWebServerRequest *request) {
      request->send_P(200, "text/plain", String(watts).c_str());
    });

    server.on("/temperature", HTTP_GET, [](AsyncWebServerRequest *request) {
      request->send_P(200, "text/plain", String(temperature).c_str());
    });

    server.begin();
  }else{  // Creating AP wifi with web server
    

    WiFi.softAP("eLOAD-WIFI", NULL);
    IPAddress IP = WiFi.softAPIP();
    //Serial.print("AP IP address: ");
    //Serial.println(IP); 

    // Web Server Root URL
    server.on("/", HTTP_GET, [](AsyncWebServerRequest *request){
      request->send(SPIFFS, "/wifimanager.html", "text/html");
    });
    
    server.serveStatic("/", SPIFFS, "/");
    
    server.on("/", HTTP_POST, [](AsyncWebServerRequest *request) {
      int params = request->params();
      for(int i=0;i<params;i++){
        AsyncWebParameter* p = request->getParam(i);
        if(p->isPost()){
          if (p->name() == PARAM_INPUT_1) {
            ssid = p->value().c_str();
            //Serial.print("SSID set to: ");
            //Serial.println(ssid);
            writeFile(SPIFFS, ssidPath, ssid.c_str());  // Write file to save value
          }
          if (p->name() == PARAM_INPUT_2) {
            pass = p->value().c_str();
            //Serial.print("Password set to: ");
            //Serial.println(pass);
            writeFile(SPIFFS, passPath, pass.c_str());  // Write file to save value
          }
        }
      }
      request->send(200, "text/plain", "Done. ESP will restart, connect to your router. Connect to IP indicated on oled screen.");// + ip);
      delay(1000);
      ESP.restart();
    });
    server.begin();
  }


  delay(1000);

  IPAddress myIP = WiFi.localIP();
  adresa = String(myIP[0]) + String(".") + String(myIP[1]) + String(".") + String(myIP[2]) + String(".") + String(myIP[3])  ;
  //imprimeixOled(adresa, display);
  botoInici=false;
 
  //******************** START INTERRUPTIONS ***********************
  attachInterrupt(digitalPinToInterrupt(SELECTOR_MOVE_A_PIN), doEncode, RISING);
  //attachInterrupt(digitalPinToInterrupt(SELECTOR_MOVE_B_PIN), doEncode, RISING);
  attachInterrupt(digitalPinToInterrupt(SELECTOR_BUTTON_PIN), encoderButton, FALLING);
  ITimer0.attachInterruptInterval(TIMER0_INTERVAL_MS * 1000, TimerHandler0);


  currentTime = millis();
}


//******************** LOOP ****************************** LOOP **************************** LOOP **********************************
void loop(){


//******************** MONITORING ***********************
  readAmps(&amps);
  readvolts(&volts);
  readPower(&volts, &amps, &watts);
  readTemp(&temperature);
  readSwitch(&gateSwitch, digitalRead(GATE_SWITCH_PIN));

  if(millis() >= (currentTime + oneSecondTime)){
    if(botoInici != true){
      if(adresa!="0.0.0.0"){
        imprimeixOled(adresa, display);
      }else{
        imprimeixOled("AP: 192.168.4.1", display);
      }
    }else{
      imprimeixOledValors(&amps, &volts, &watts, &gateSwitch, display);
    }
    currentTime = millis();
  }



  
//******************** SERIAL PWM ***********************
/*  if (Serial.available() > 0) {
    int incomingvalue = Serial.parseInt();    
    if(incomingvalue > 0){
      if(incomingvalue == 300){
        PWM = 0;
      }else{
        PWM = incomingvalue;
      } 
      analogWrite(PWM_PIN,PWM);           
    }
    
  }*/

  delay(100);
}

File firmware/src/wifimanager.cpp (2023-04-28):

#include <wifimanager.h>
#include <Arduino.h>
#include <WiFi.h>
#include <ESPAsyncWebServer.h>
#include <AsyncTCP.h>
#include "SPIFFS.h"


//******************** INITIALIZE SPIFFS ***********************
void initSPIFFS() {
  if (!SPIFFS.begin(true)) {
    //Serial.println("An error has occurred while mounting SPIFFS");
  }
  //Serial.println("SPIFFS mounted successfully");
}


//******************** READ FILE FROM SPIFFS ***********************
String readFile(fs::FS &fs, const char * path){
  //Serial.printf("Reading file: %s\r\n", path);

  File file = fs.open(path);
  if(!file || file.isDirectory()){
    //Serial.println("- failed to open file for reading");
    return String(); 
  }
  
  String fileContent;
  while(file.available()){
    fileContent = file.readStringUntil('\n');
    break;     
  }
  return fileContent;
}


//******************** WRITE FILE TO SPIFFS ***********************
void writeFile(fs::FS &fs, const char * path, const char * message){
  //Serial.printf("Writing file: %s\r\n", path);

  File file = fs.open(path, FILE_WRITE);
  if(!file){
    //Serial.println("- failed to open file for writing");
    return;
  }
  if(file.print(message)){
    //Serial.println("- file written");
  } else {
    //Serial.println("- frite failed");
  }
}


//******************** INITIALIZE WIFI ***********************
bool initWiFi(String ssid, String pass, unsigned long previousMillis, const long interval) {
  if(ssid==""){// || ip==""){
    //Serial.println("Undefined SSID");
    return false;
  }

  WiFi.mode(WIFI_STA);

  WiFi.begin(ssid.c_str(), pass.c_str());
  //Serial.println("Connecting to WiFi...");

  unsigned long currentMillis = millis();
  previousMillis = currentMillis;

  while(WiFi.status() != WL_CONNECTED) {
    currentMillis = millis();
    if (currentMillis - previousMillis >= interval) {
      //Serial.println("Failed to connect.");
      return false;
    }
  }

  //Serial.println(WiFi.localIP());
  return true;
}

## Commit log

2023-04-13 base
    - tot el que havia fet en local
    - pantalla oled + web spiffs + wifi manager
2023-04-13 digital led
    afegit digital led al main, encara no funciona be, els colors fallen
2023-04-16 millor web
    - separar html, css i js
    - imprimir IP per pantalla
    [huge_app.csv]
2023-04-17 Thermistor
    implementació de la lectura del termistor, amb algoritme.
    web actualitzada per mostrar temperatura
2023-04-18 primitive sensor filter
    mitjana dels ultims 10 valors llegits
2023-04-18 schematic description
2023-04-19 Calculation file
    added
    [calculations.xlsx]
2023-04-19 ADC sense
    el ADC del ESP32-C3 te una desviació del 10%!!
    [calculations.xlsx]
2023-04-20 ADC sensing
    ajustament de l'atenuació del ADC, millora la lectura de V i A, pero s'ha d'arreglar Temperatura
    [main.cpp]
2023-04-21 thermistor and protections
    solucionat calcul de la temperatura amb el termistor, i protecció per temperatura, que s'haura de fer amb interrupcions
2023-04-25 main display screen
    pantalla principal, gate switch sense, variables amb punters...
    patalla inici amb ip fins apretar el boto...
2023-04-25 description and hw files
    [BOM_PCB_Electronic-load_2023-04-25.csv]
2023-04-25 change pwm by rotary
2023-07-02 some temperature protections
2024-01-10 added release and download tags buttons
